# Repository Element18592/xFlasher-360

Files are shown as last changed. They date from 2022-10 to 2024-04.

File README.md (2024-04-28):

<h1 align="center">xFlasher 360</h1>
<p align="center">
  
</p>

## Description
  
- Nearly 3 times faster than the NAND-X
- An all in one design compatible with every Xbox 360 motherboard
- Easily toggle between SPI and eMMC mode with the flip of a switch
- Reads/writes 4GB NANDs in 5 seconds
- Reads/writes 16MB NANDs in under 50 seconds
- No more single use 4GB QSB's
- Native integration with the J-Runner with Extras software
- Flashing compatibility for all Xilinx based glitch chips including the Ace V3, Coolrunner, Matrix, etc
- Native Windows x64 drivers, no more hassling with unsigned drivers

## Product Page
https://themodshop.co/shop/xflasher.html
  
## Questions
✉️ Contact me with any questions: [email](mailto:support@themodshop.co)<br />

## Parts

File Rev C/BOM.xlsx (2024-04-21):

 |  |  |  | Rev C
Quantity | Reference Designator | Manufacturer | Manufacturer Part Number | Description
8 | C1, C2, C3, C5, C9, C10, C11, C15 | TDK Corporation | CGJ4J2X7R1H104K125AA | CAP CER 0.1UF 50V X7R 0805
4 | C4, C6, C7, C16 | TDK Corporation | CGA4J3X7S1A106M125AB | CAP CER 10UF 10V X7S 0805
1 | C8 | TDK Corporation | CGB4B1X5R1E225K055AC | CAP CER 2.2UF 25V X5R 0805
1 | C12 | TDK Corporation | CGJ4J2X7R1C105K125AA | CAP CER 1UF 16V X7R 0805
2 | C13, C14 | AVX Corporation | 08055C270KAT2A | CAP CER 27PF 50V X7R 0805
4 | R1, R2, R4, R6 | Bourns Inc. | CR0805-FX-1001ELF | RES SMD 1K OHM 1% 1/8W 0805
4 | R3, R11, R12, R13 | Stackpole Electronics Inc | RMCF0805JG10K0 | RES 10K OHM 5% 1/8W 0805
1 | R5 | Panasonic Electronic Components | ERA-6ARB123V | RES 12K OHM 0.1% 1/8W 0805
1 | R7 | Bourns Inc. | CR0805-FX-68R0ELF | RES SMD 68 OHM 1% 1/8W 0805
2 | R8, R9 | Meritek | CR105101F | RES SMD 5.1K OHM 1% 1/8W 0805
1 | U1 | FTDI | FT2232HL | IC USB HS DUAL UART/FIFO 64-LQFP
1 | U2 | Genesys Logic | GL823K SSOP16 | SSOP-16 USB IC
1 | U3 | ON Semiconductor | FSUSB30MUX | IC USB SWITCH 2X2 10MSOP
1 | U4 | Texas Instruments | TLV74033PDBVR | IC REG LINEAR 3.3V 300MA SOT23-5
1 | J1 | Korean Hroparts Elec | TYPE-C-31-M-12 | CONN RCPT Female Type-C SMD USB
1 | J2 | JST Sales America Inc. | S6B-ZR-SM4A-TF(LF)(SN) | CONN HEADER SMD R/A 6POS 1.5MM
1 | J3 | JST Sales America Inc. | S7B-ZR-SM4A-TF(LF)(SN) | CONN HEADER SMD R/A 7POS 1.5MM
1 | J4 | JST Sales America Inc. | S9B-ZR-SM4A-TF(LF)(SN) | CONN HEADER SMD R/A 9POS 1.5MM
2 | L1, L2 | Dialight | 5990191007F | LED BLUE 0805 SMD
1 | X1 | Abracon LLC | ABM3-12.000MHZ-D2Y-T | CRYSTAL 12.0000MHZ 18PF SMD
1 | S1 | Use Generic | MSK-12C02 | MINI SLIDE SWITCH 6.7 X 2.7 MM.
1 | R10 | Stackpole Electronics Inc | RMCF0805JT2K00 | RES 2K OHM 5% 1/8W 0805
1 | U5 | Microchip Technology | 93LC56BT-I/OT | IC EEPROM 2KBIT MIC WIRE SOT23-6
1 | FT_RST | Würth Elektronik | 436331045822 | SWITCH TACTILE SPST-NO 0.05A 12V

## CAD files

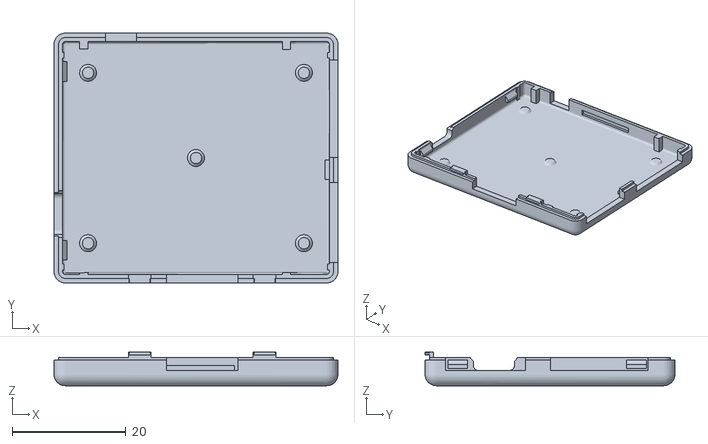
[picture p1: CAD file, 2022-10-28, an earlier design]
Rev B/Case Files/Bottom.stl
50.0 x 44.0 x 5.90

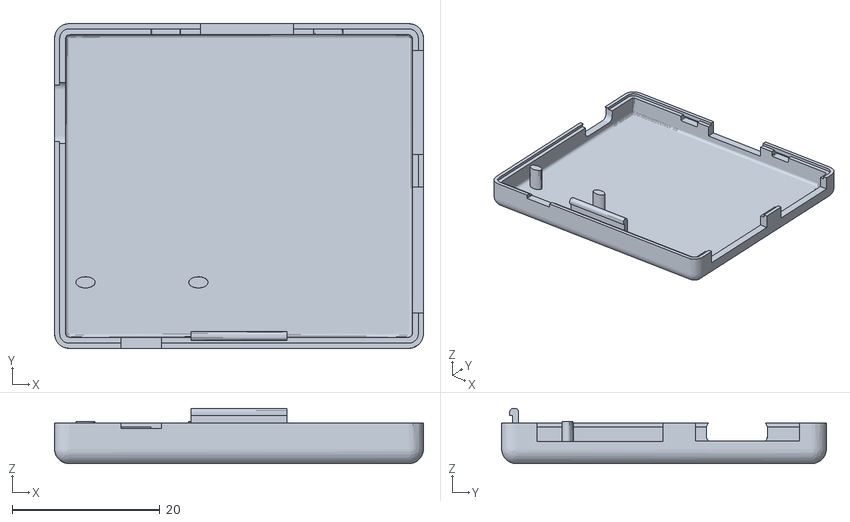
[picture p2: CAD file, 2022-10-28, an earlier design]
Rev B/Case Files/Top.stl
50.0 x 44.0 x 7.50

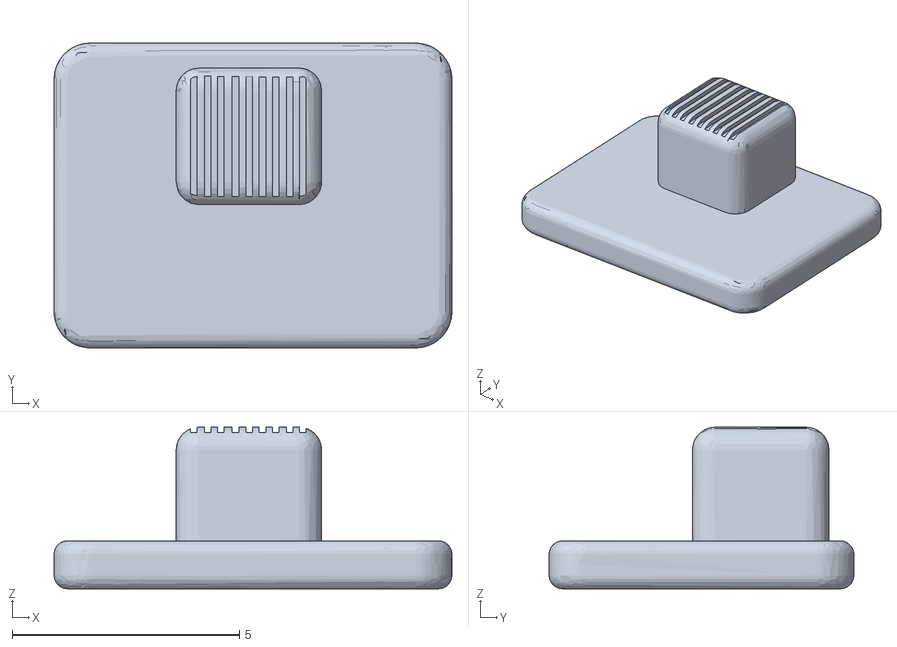
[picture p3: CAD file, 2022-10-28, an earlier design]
Rev B/Case Files/Cap.stl
8.76 x 6.71 x 3.56

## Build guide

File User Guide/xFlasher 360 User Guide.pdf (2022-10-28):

# xFlasher 360 User Guide

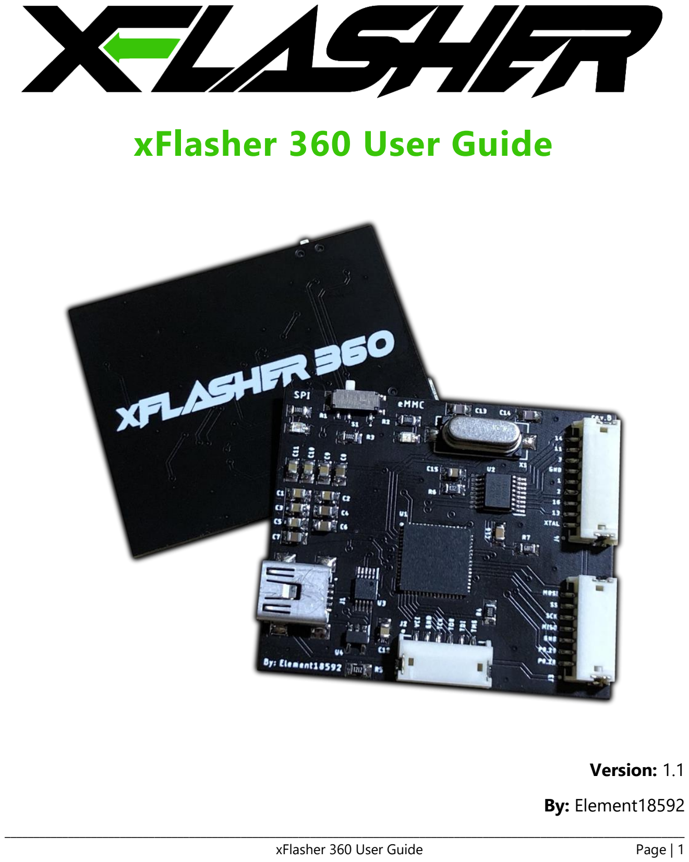
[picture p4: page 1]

______________________________________________________________________________________________________________________
xFlasher 360 User Guide | Page | 1

### Version: 1.1

### By: Element18592

## Table of Contents

# Introduction

## About the xFlasher

- Twice as fast as the NAND-X
- An all-in-one design compatible with every Xbox 360 motherboard
- Easily toggle between SPI and eMMC mode with the flip of a switch
- Reads/writes 4GB NANDs in 5 seconds
- Reads/writes 16MB NANDs in under 50 seconds; 512MB in under 4 minutes
- No more single use 4GB QSB's
- Native integration with the J-Runner with Extras software
- Flashing compatibility for all Xilinx based glitch chips including the Ace V3, Coolrunner, Matrix, etc.
- Native Windows x64 drivers, no more hassling with unsigned drivers

## System Requirements

- Microsoft Windows Vista Service Pack 2 or later
- USB 2.0 Compliant PC

## What’s Included in the Box

The xFlasher 360 includes the following items in the package:

- 1.) JTAG Cable
- 2.) eMMC Cable
- 3.) SPI Cable
- 4.) xFlasher 360

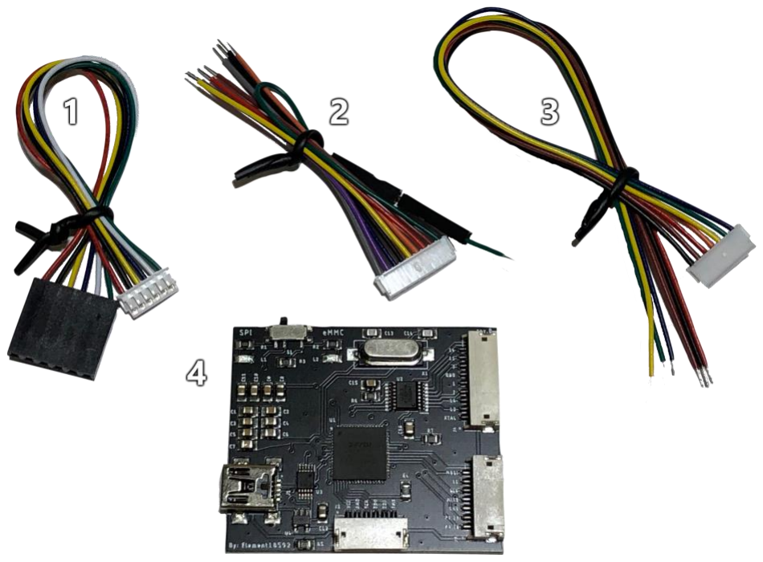
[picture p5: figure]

# Pinouts

## JTAG Cable Pinout

The following cable should be used when programming various glitch chips.

Cable Color | Usage
Green | TMS
White | TDI
Blue | TDO
Yellow | TCK
Black | GND
Red | VCC

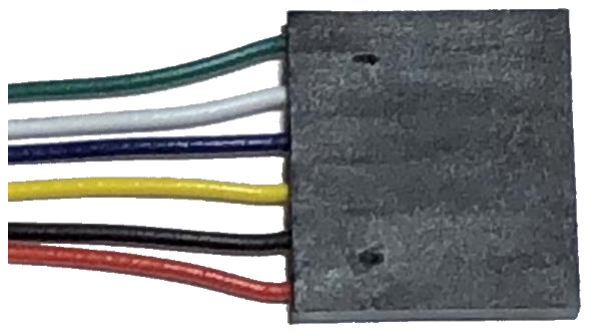
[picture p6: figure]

## X360ACE V3 Pinout Example:

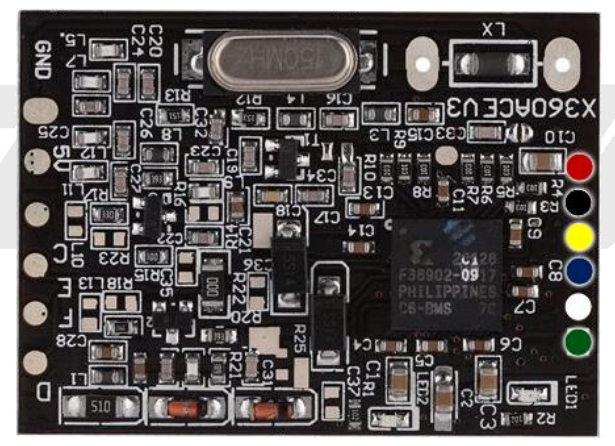
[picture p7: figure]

## Coolrunner Pinout Example:

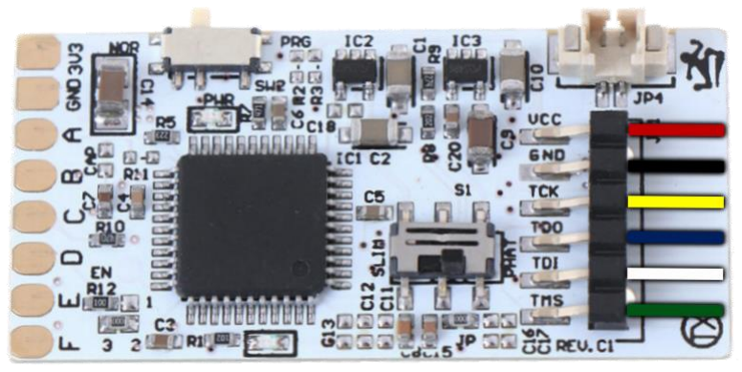
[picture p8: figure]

## 4GB eMMC Cable Pinout

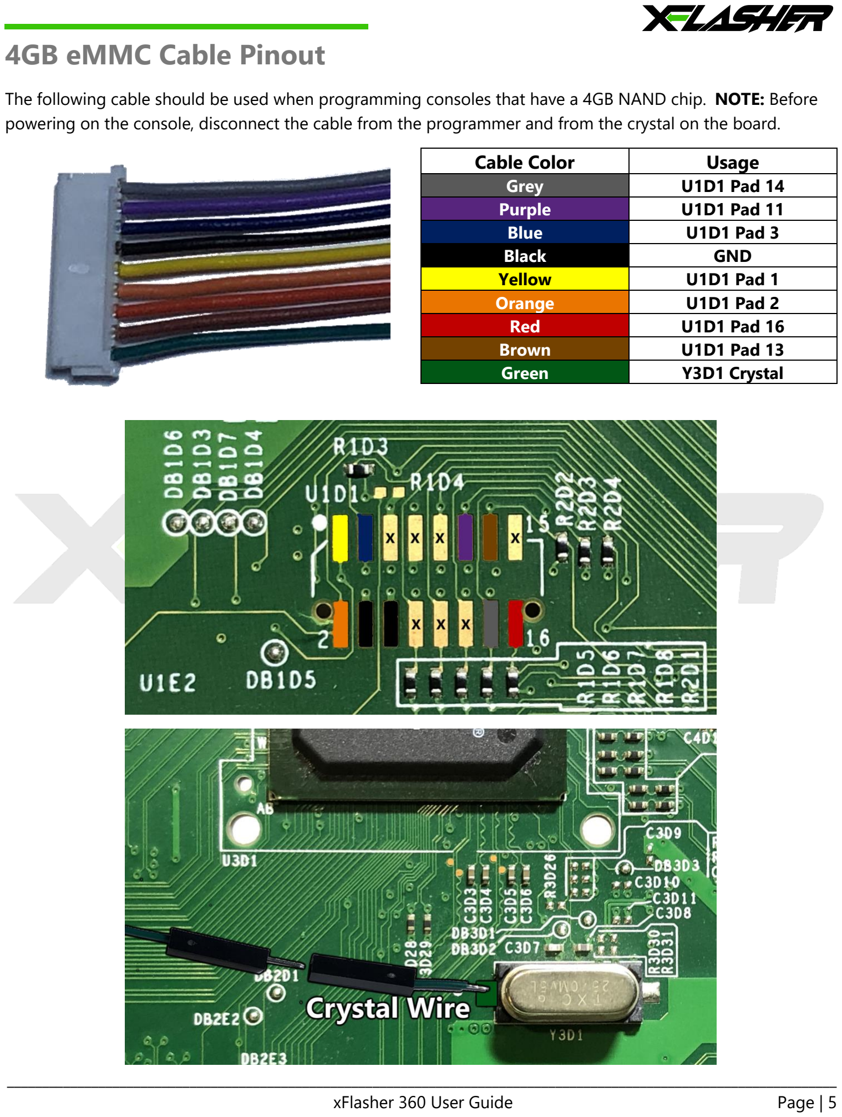
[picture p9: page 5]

The following cable should be used when programming consoles that have a 4GB NAND chip. NOTE: Before powering on the console, disconnect the cable from the programmer and from the crystal on the board.

Cable Color | Usage
Grey | U1D1 Pad 14
Purple | U1D1 Pad 11
Blue | U1D1 Pad 3
Black | GND
Yellow | U1D1 Pad 1
Orange | U1D1 Pad 2
Red | U1D1 Pad 16
Brown | U1D1 Pad 13
Green | Y3D1 Crystal

## 16/256/512MB SPI Cable Pinout

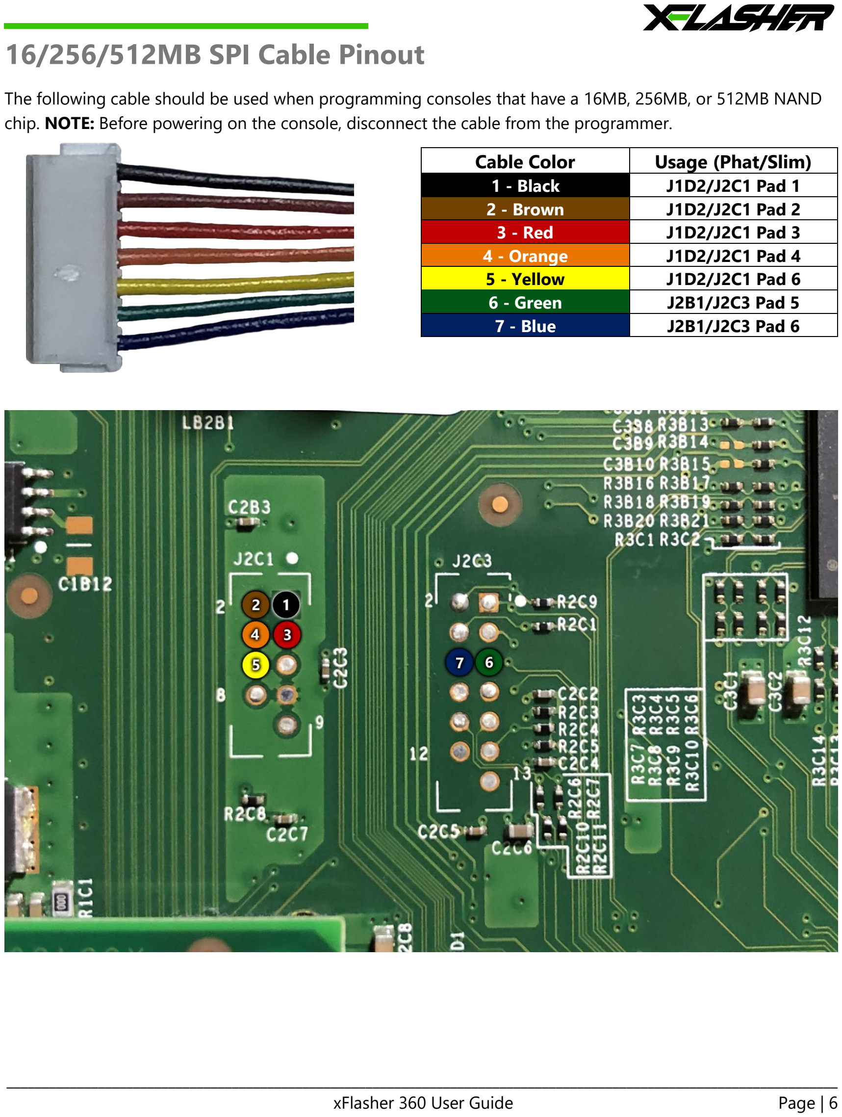
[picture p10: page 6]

The following cable should be used when programming consoles that have a 16MB, 256MB, or 512MB NAND chip. NOTE: Before powering on the console, disconnect the cable from the programmer.

Cable Color | Usage (Phat/Slim)
1 - Black | J1D2/J2C1 Pad 1
2 - Brown | J1D2/J2C1 Pad 2
3 - Red | J1D2/J2C1 Pad 3
4 - Orange | J1D2/J2C1 Pad 4
5 - Yellow | J1D2/J2C1 Pad 6
6 - Green | J2B1/J2C3 Pad 5
7 - Blue | J2B1/J2C3 Pad 6

# Driver Installation

The following steps need to be performed to install the driver required to use xFlasher 360:

1. Download the latest driver installer.
2. Navigate to the downloads location and execute xFlasher-Drivers.exe
3. The installation wizard will launch. On the first page, click the Extract button. The wizard will copy some files to a temporary directory and then the Device Driver Installation Wizard will launch.

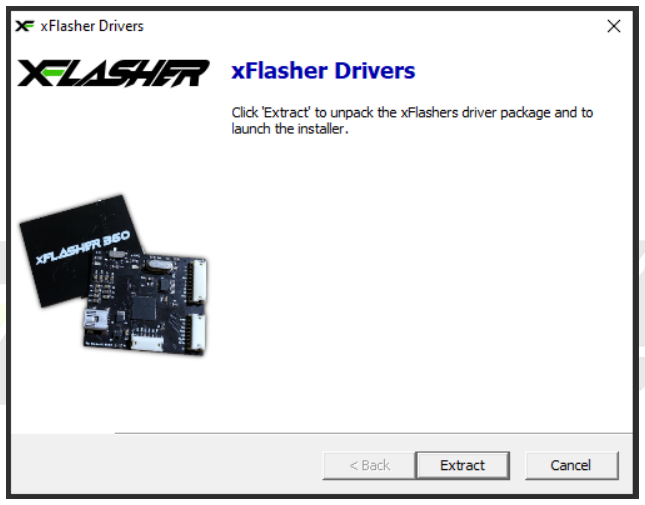
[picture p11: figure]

4. When the Device Driver Installation Wizard launches, click the Next button.

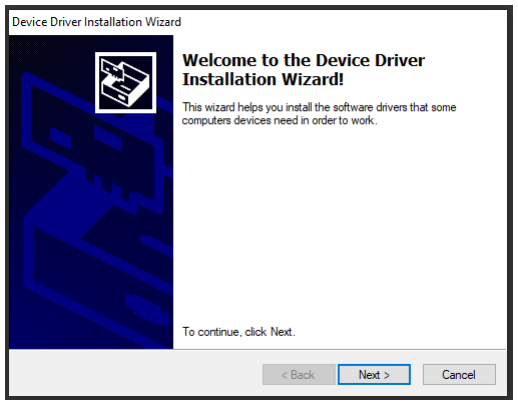
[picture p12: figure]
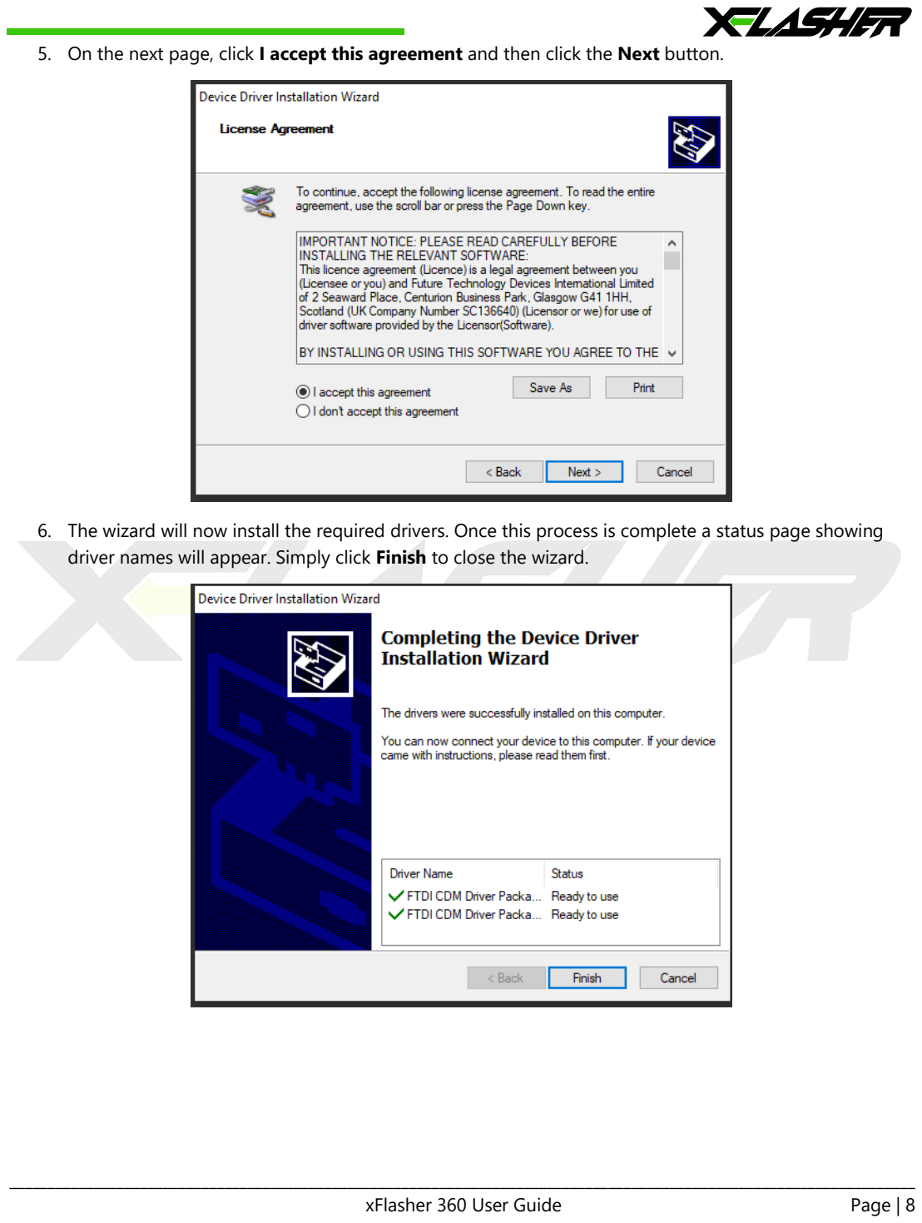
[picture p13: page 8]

5. On the next page, click I accept this agreement and then click the Next button.
6. The wizard will now install the required drivers. Once this process is complete a status page showing driver names will appear. Simply click Finish to close the wizard.

# Operation

NOTE: Before powering on the console, disconnect the programming cable between the xFlasher and the console. If it is a 4GB eMMC NAND, disconnect the crystal on the board with the built-in break-away cable.

## 4GB eMMC NAND Usage

1. Solder the eMMC read/write cable to the motherboard
2. Connect power to the console
3. Connect the xFlasher to the eMMC read/write cable
4. Connect the xFlasher to PC via a USB cable

## 16/256/512MB NAND Usage

1. Solder the SPI read/write cable to the motherboard
2. Connect power to the console
3. Connect the xFlasher to the SPI read/write cable
4. Connect the xFlasher to PC via a USB cable

## Programming Glitch Chips

Note: The xFlasher can ONLY program SVF timing files; these are included in J-Runner with Extras.

1. The Xbox 360 console must be plugged in but NOT powered on when programming the glitch chip.
2. When launching J-Runner with Extras for the first time on your PC, you may receive a prompt to install the required Visual Studio Redistributable. Click OK to begin the installation.

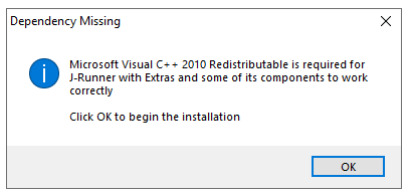
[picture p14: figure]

3. Before you can program a glitch chip, it is mandatory that the switch on the top of the xFlasher is set to the SPI mode.
4. Refer to the specifics for your console/glitch type for further instructions.

## Programming Console Nands

1. The Xbox 360 console must be plugged in but NOT powered on when programming the NAND.
2. Before you can program a console NAND, flip the switch on the top of the xFlasher to the desired mode (eMMC for 4GB NANDS, SPI for 16/256/512MB NANDS). The corresponding mode will appear in J-Runner with Extras on your PC as shown below.

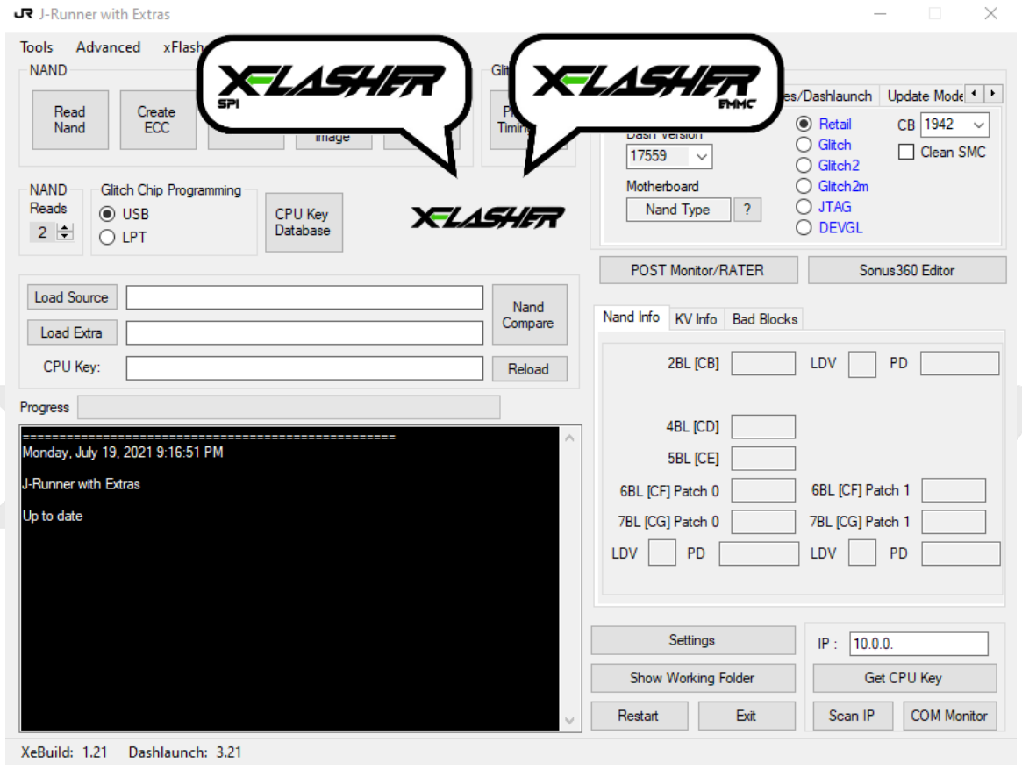
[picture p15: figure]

3. Refer to the specifics for your console/exploit type for further instructions.

# Thank You for Purchasing

# We Hope You Enjoy Our Product!
